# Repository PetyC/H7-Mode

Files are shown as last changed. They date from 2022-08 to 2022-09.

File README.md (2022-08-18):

<!--
 * @Description: Pi
 * @Autor: Pi
 * @Date: 2022-04-13 19:11:35
 * @LastEditTime: 2022-08-18 17:58:05
-->
# H7-Mode  
本项目名叫H7-Mode,顾名思义就是采用STM32H7作为MCU芯片进行相关设计开发的核心板和一些配套模组。  
意在实现具有联网、在线OTA升级、MQTT、LCD小屏状态显示等等功能的高性能面向自己的物联网开发核心套装，可根据不同要求设计不同底板以快速实现不同的功能。
因考虑到价格和设计难度，本项目使用芯片具体型号为STM32H7VIT6。
****

## 一、硬件部分
### 1.硬件结构
本项目目前分为H7-Core和H7-Network两个模块，Core实现核心功能，Network主要实现网络功能。
后续可能会加入更多的模块到该项目中以实现更多的功能  
模块之间通过FPC排线连接，并通过2.5mm螺柱固定成整体
### 2.整体外观  
本项目所设计PCB尺寸较小，长5cm 宽3cm。因考虑成本故只采用了双层板设计，也因此限搭载硬件资源有限。
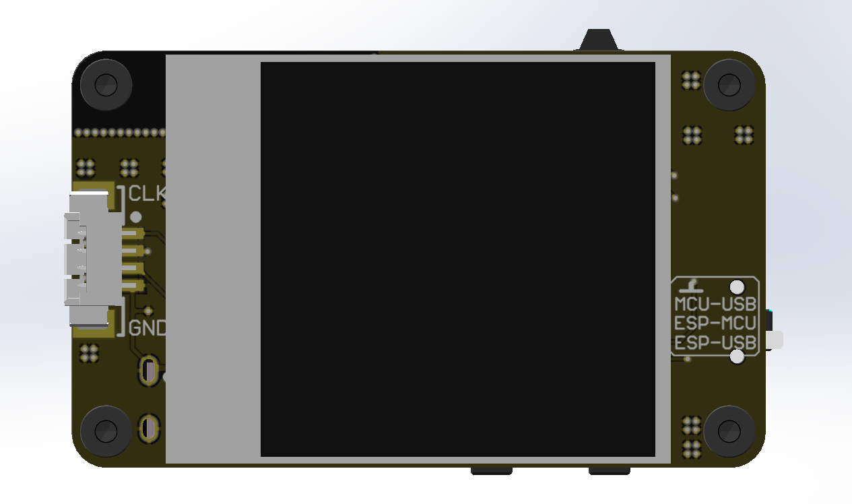
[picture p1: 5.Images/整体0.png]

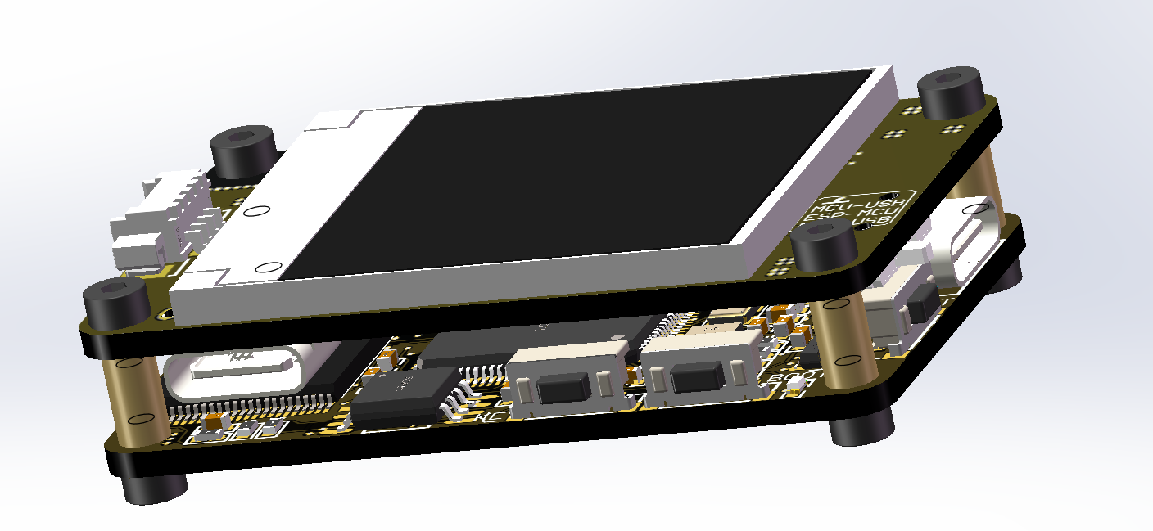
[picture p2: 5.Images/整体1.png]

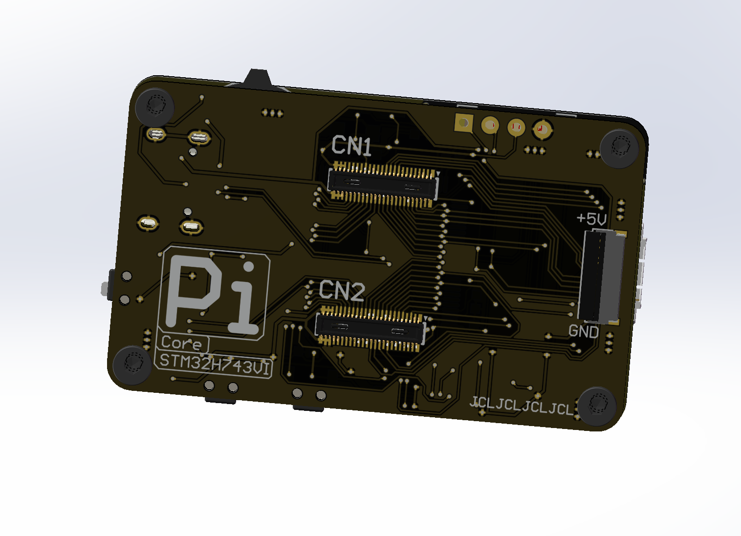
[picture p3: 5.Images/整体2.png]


****
### 2.硬件资源
#### 1.H7-Core
①MCU主频480MHZ 片内2MB FALSH、1MB RAM  
②板载高速、低速时钟  
③板载W25QXX FLASH 采用四线连接，走QSPI协议，芯片容量型号可自行更换  
④板载NAND FLASH  可做数据存储
⑤采用Type-C供电 支持USB2.0  
⑥共有3个按键，分别为:用户自定义按键、复位按键、一键进入Boot按键(即一键就可进入BOOT模式，无需长按或与复位键组合按)    
⑦2个LED，用户均可自定义功能  
⑧5V供电具有正反防短路电路，但需要注意3V3无任何保护  
⑨采用DC40F系列连接器，共引出80个IO和3V3，5V供电
#### 2.H7-Network
①MCU为ESP8266(可替换为ES8285) 使用26MHZ晶振  
②板载W25Q系列FLASH 采用4线连接，可使用QIO模式运行，FLASH型号可自行更换    
③板载陶瓷天线，比常见PCB天线信号更好  
④板载CP2102 USB转串口芯片  
⑤设计有自动下载电路，可实现固件自动下载  
⑥板载多通道开关芯片，可通过开关切换串口连接对象(MCU-ESP、MCU-CP2102、ESP-CP2102)，方便进行调试等工作  
⑦2个LED，用户均可自定义功能  
⑧板载3挡波轮开关，用户可自定义3挡功能  
⑨采用Type-C接口供电、连接电脑  
⑩搭载1.44寸TFT屏幕，其显示工作由H7-Core负责，本身未与ESP8266相连  

### 3.固件开发
#### 1.H7-Core    开发中  
整体框架使用STM32Cubmex+HAL进行开发（待续
#### 2.H7-Network 开发中  
整体框架在AT环境下进行开发，其使用源码为乐鑫提供的AT工程以实现一些自定义AT指令（待续

### 4.软件开发
#### 1.H7-Tool 微信小程序
初步实现配网功能，可使用微信小程序给H7-Mode设置WIFI网络信息，实现联网，界面如下  
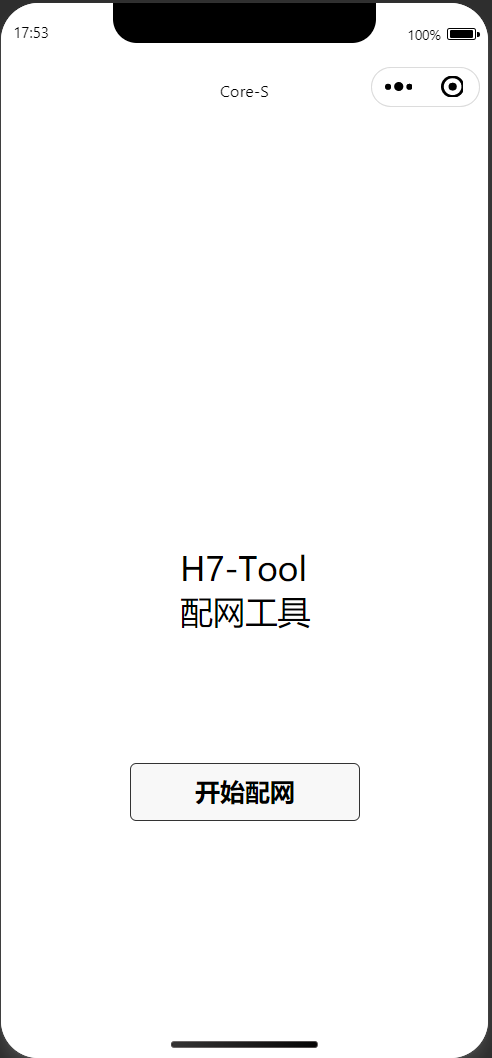
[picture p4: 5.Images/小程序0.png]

#### 2.待续  

### 4.待续待续待续待续
注:本项目所有资料尚未整理完毕

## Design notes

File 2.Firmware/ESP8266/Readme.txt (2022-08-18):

1、标准AT固件：存放有乐鑫官方提供的1.71版本AT固件
2、自定义AT固件: 存放有修改后的AT固件(1MB)
3、flash_download_tool_3.9.2 串口烧录工具
主要增加了按键检测功能和LED功能
按键检测:AT+KEY=1 启用，AT+KEY=0 关闭;
当有按键按下时，串口回复KEY:按键号\r\n

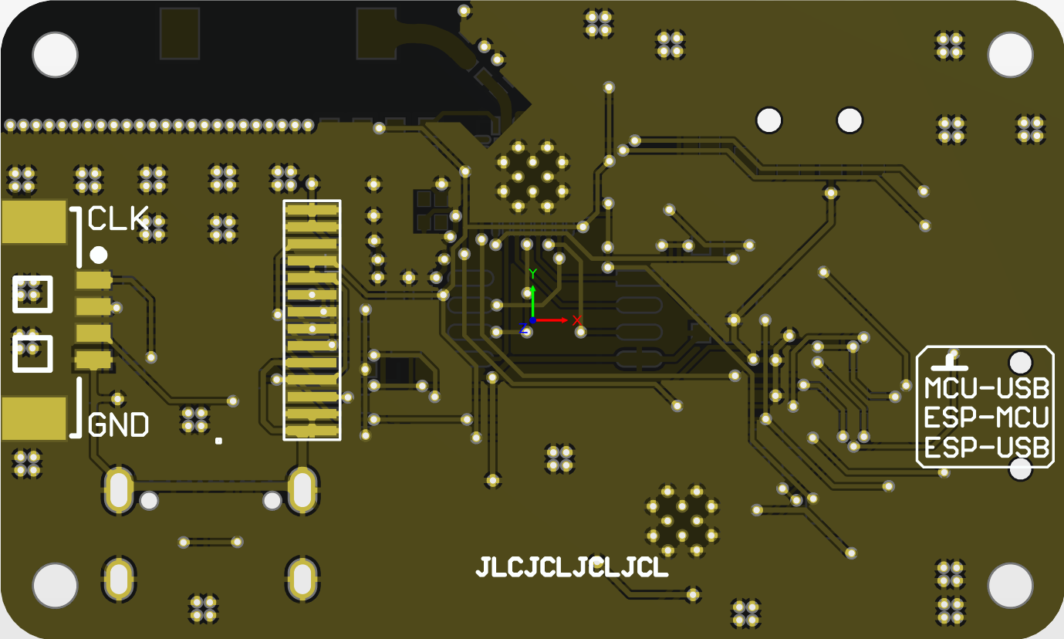
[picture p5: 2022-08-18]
1.Hardware/PCB_3D/PCB_Model/贴图/扩展版TOP贴图.png

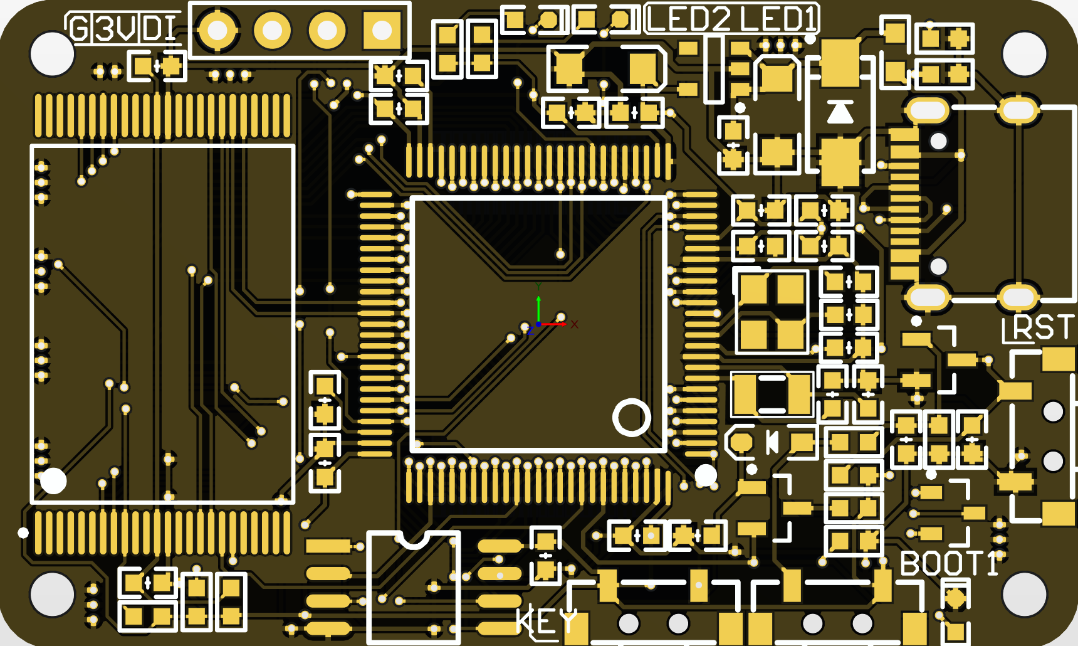
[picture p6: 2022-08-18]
1.Hardware/PCB_3D/PCB_Model/贴图/Core-TOP贴图.png

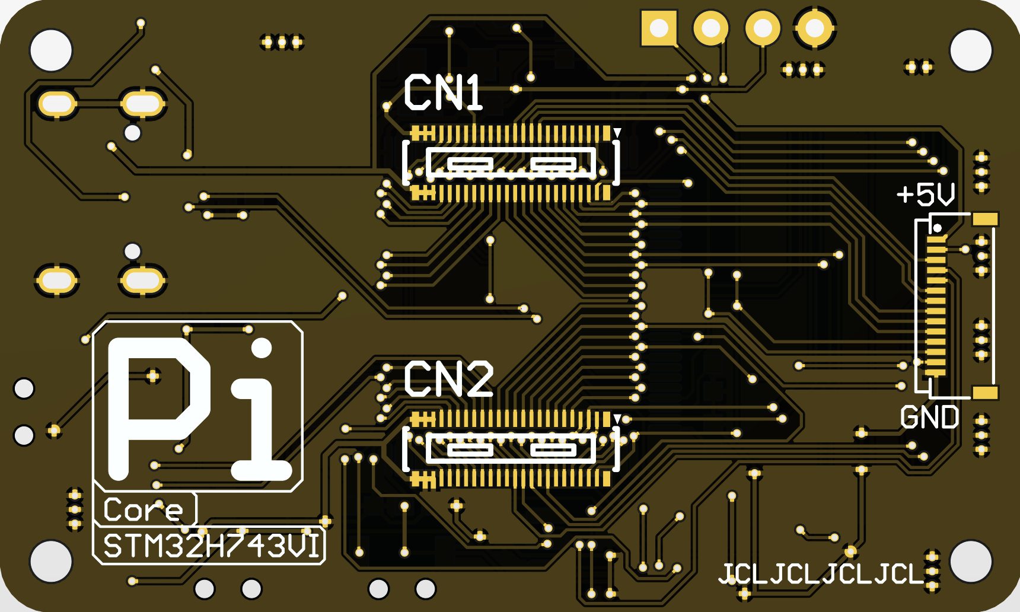
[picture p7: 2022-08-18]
1.Hardware/PCB_3D/PCB_Model/贴图/Core-Bottom贴图.png

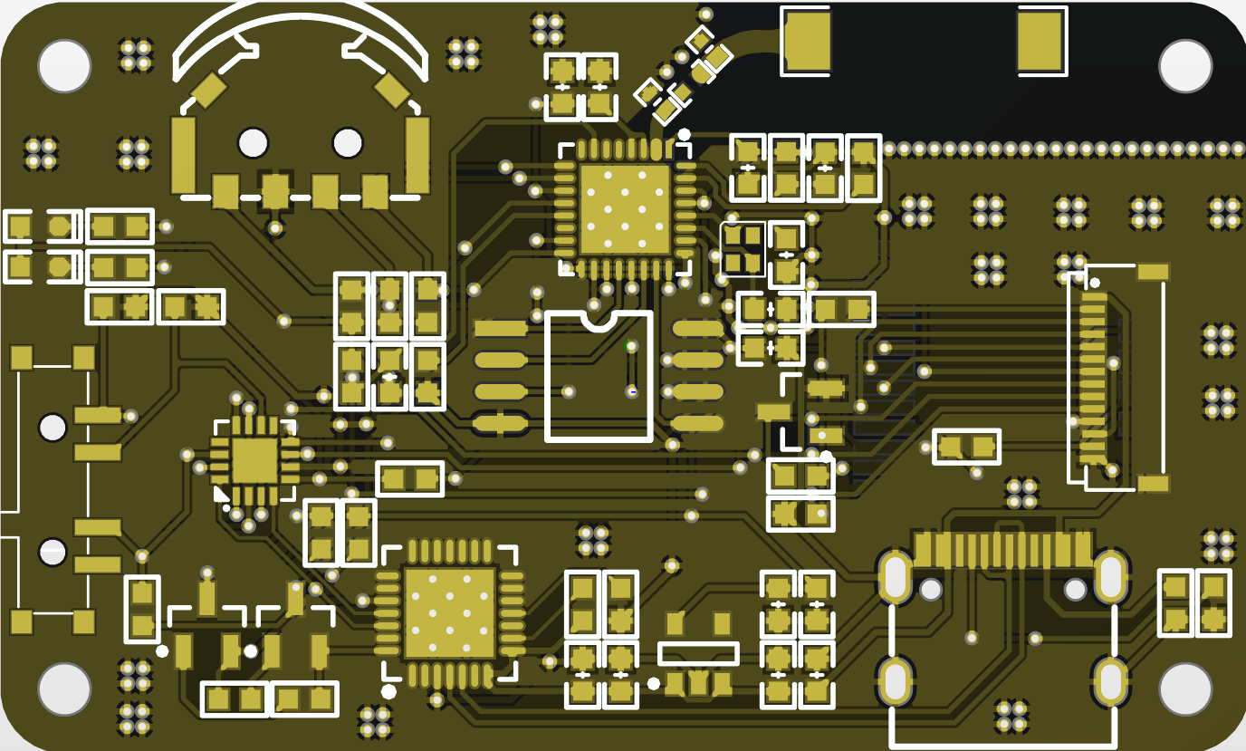
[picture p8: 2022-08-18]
1.Hardware/PCB_3D/PCB_Model/贴图/扩展版Bottom贴图.png

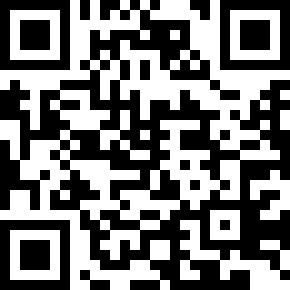
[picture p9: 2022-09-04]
2.Firmware/LVGL/CoreH7/generated/images/QR.png

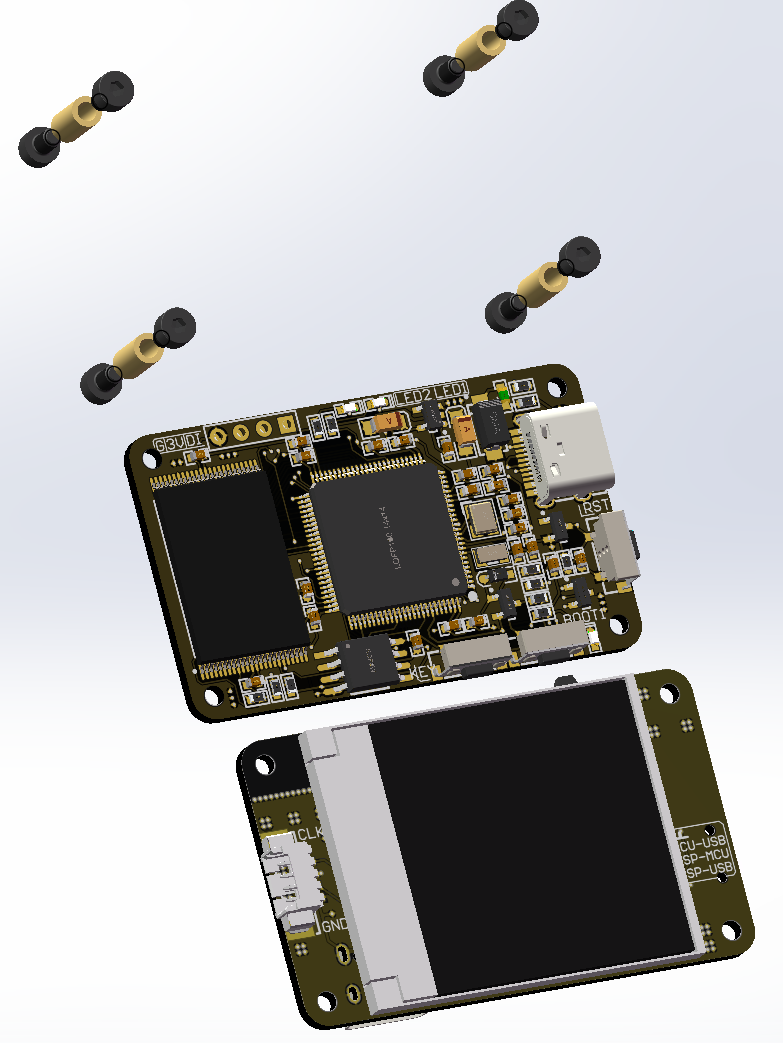
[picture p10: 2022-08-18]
5.Images/解体0.png

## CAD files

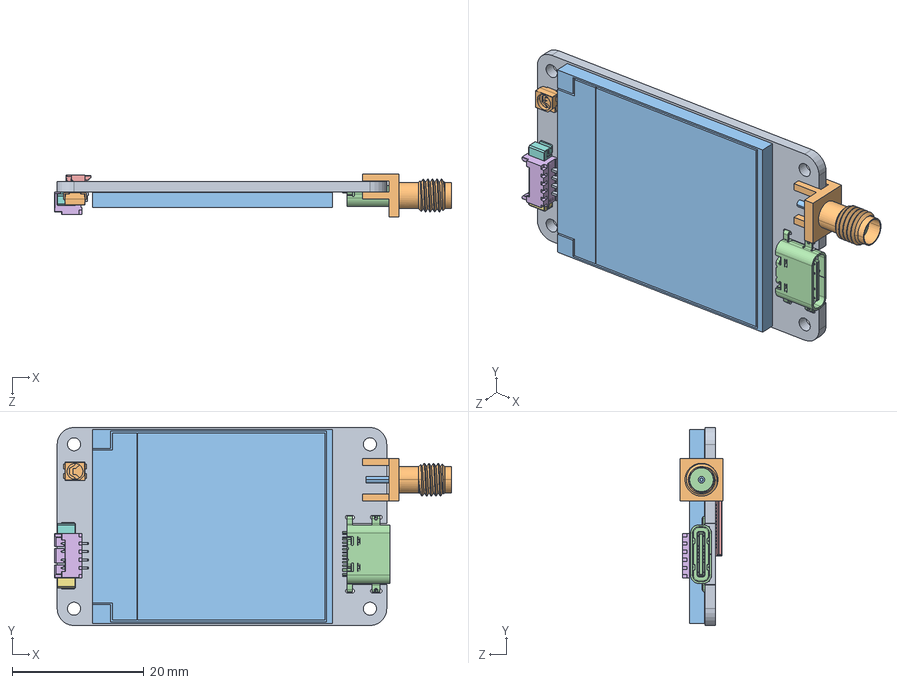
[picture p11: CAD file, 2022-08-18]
1.Hardware/PCB_3D/PCB_Model/Shape_Test.step.SLDASM
60.4 x 30.1 x 6.50 mm
_10001.step
_6_10001.step
_30001.step
FH34SRJ-14S-0.5SH(50).step
_12_1_2_AF0.step
4_1_200.step
1_1_200.step
MOLEX1_25-WS-_1_200.step x 4
LED_3528-4PIN_-675000.step
LCD_1.44.step
USB4505-03-0-A.step

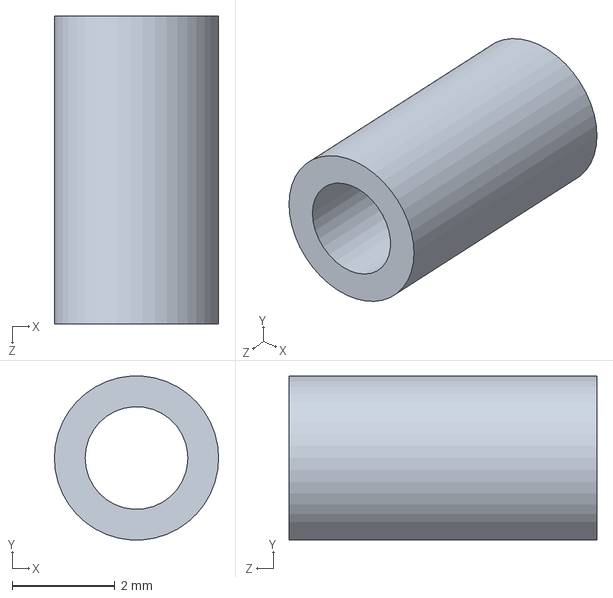
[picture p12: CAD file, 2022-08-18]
1.Hardware/PCB_3D/PCB_Model/M2铜柱.SLDPRT
3.20 x 3.19 x 6.00 mm

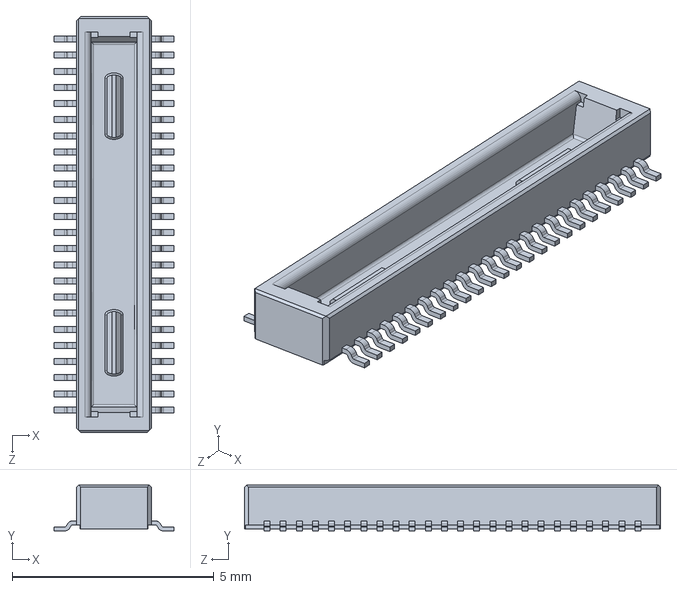
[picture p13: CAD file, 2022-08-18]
1.Hardware/PCB_3D/SLDPRT/DF40C-44DP.SLDPRT
2.97 x 1.14 x 10.3 mm

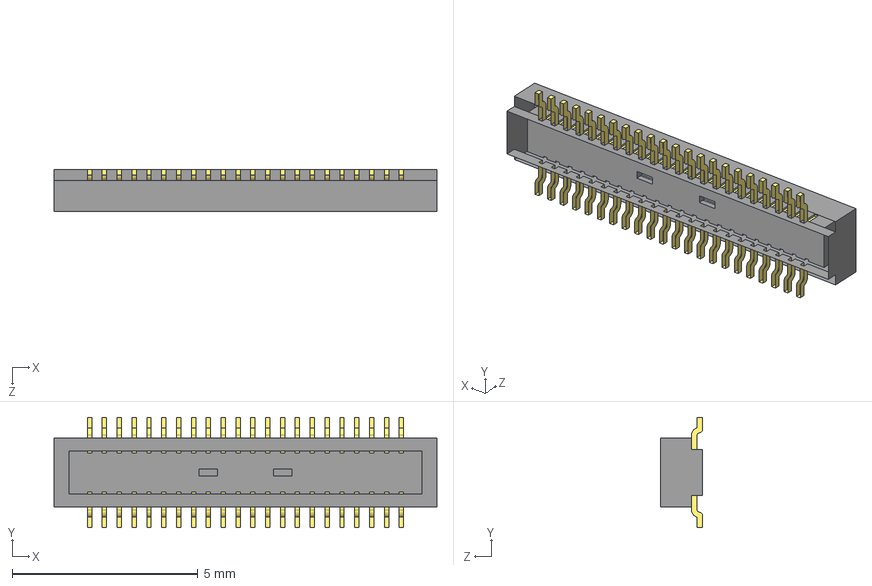
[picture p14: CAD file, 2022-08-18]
1.Hardware/PCB_3D/STEP/DF40C-44DP-0.4V.STEP
10.3 x 2.97 x 1.14 mm

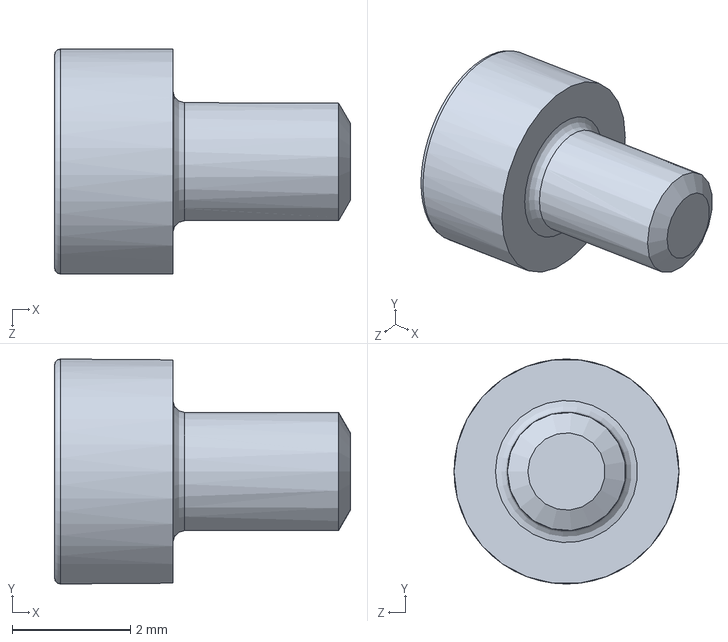
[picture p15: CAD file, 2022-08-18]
1.Hardware/PCB_3D/PCB_Model/内六角圆柱头螺钉M2.SLDPRT
5.00 x 3.80 x 3.80 mm

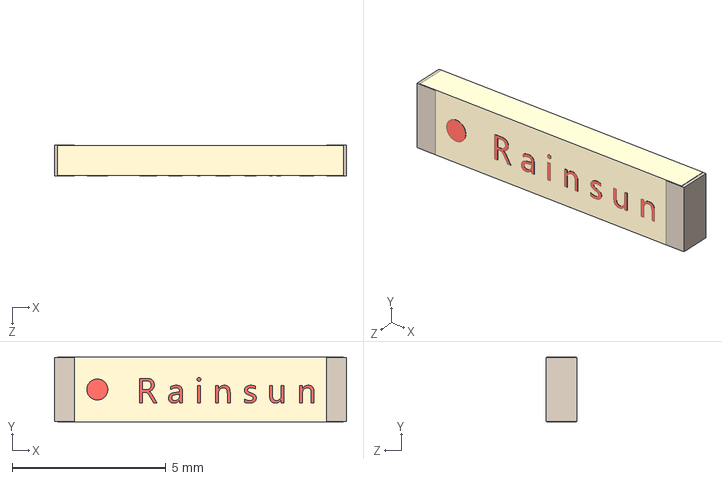
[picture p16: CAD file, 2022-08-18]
1.Hardware/PCB_3D/STEP/AN9520-245.STEP
9.50 x 2.10 x 1 mm

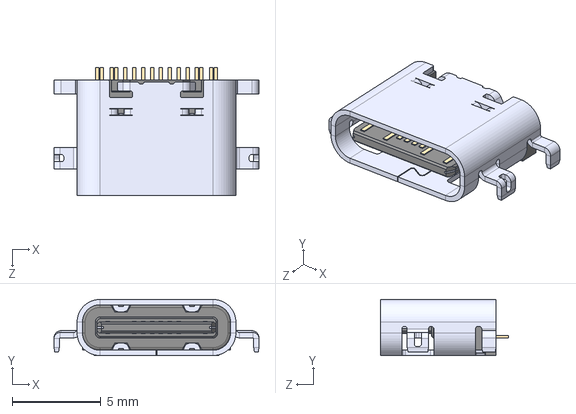
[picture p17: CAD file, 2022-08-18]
1.Hardware/PCB_3D/STEP/TYPE-C-16.STEP
11.5 x 3.16 x 7.20 mm

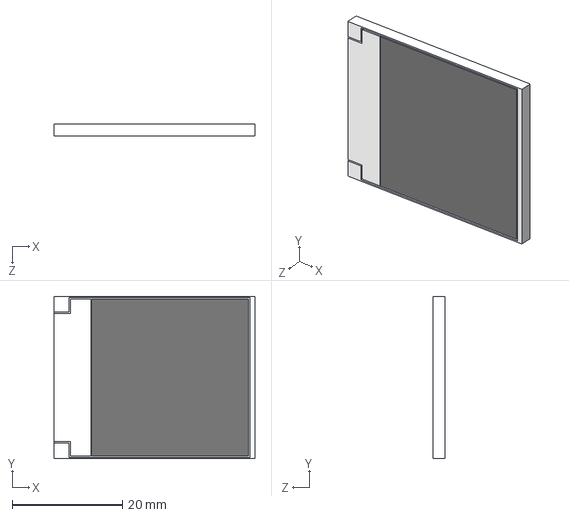
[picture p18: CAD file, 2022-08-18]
1.Hardware/PCB_3D/STEP/LCD_1.44.STEP
36.5 x 29.5 x 2.26 mm

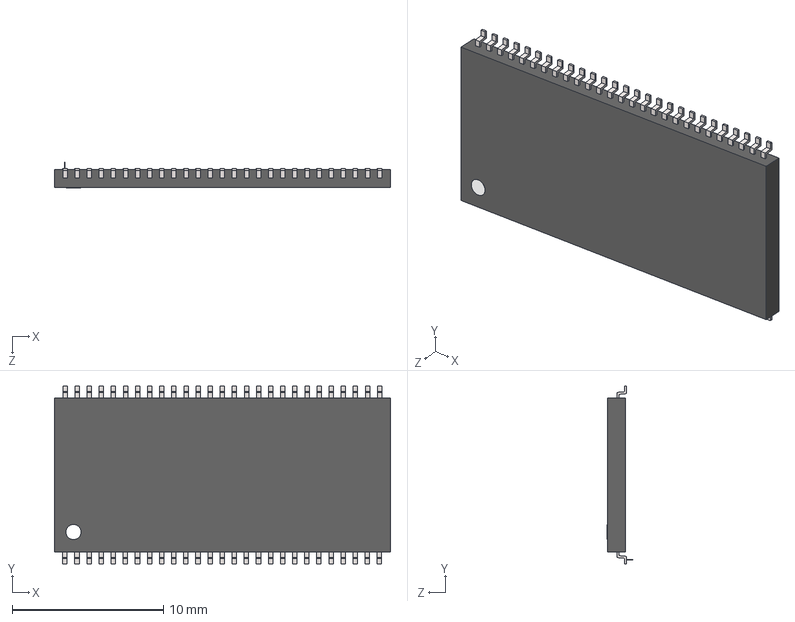
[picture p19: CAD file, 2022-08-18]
1.Hardware/PCB_3D/STEP/TSOP-54.STEP
22.2 x 11.8 x 1.70 mm
User Library-TSOP2-54-1_SW3dPS-TSOP2-54_Board5
User Library-TSOP2-54-1_SW3dPS-TSOP2-54_Extruded2 x 54
User Library-TSOP2-54-1_SW3dPS-TSOP2-54_Board4 x 54
User Library-TSOP2-54-1_SW3dPS-TSOP2-54_Extruded3
User Library-TSOP2-54-1_SW3dPS-TSOP2-54_Board7
User Library-TSOP2-54-1_SW3dPS-TSOP2-54_Cylinder1
User Library-TSOP2-54-1_SW3dPS-TSOP2-54_Board6

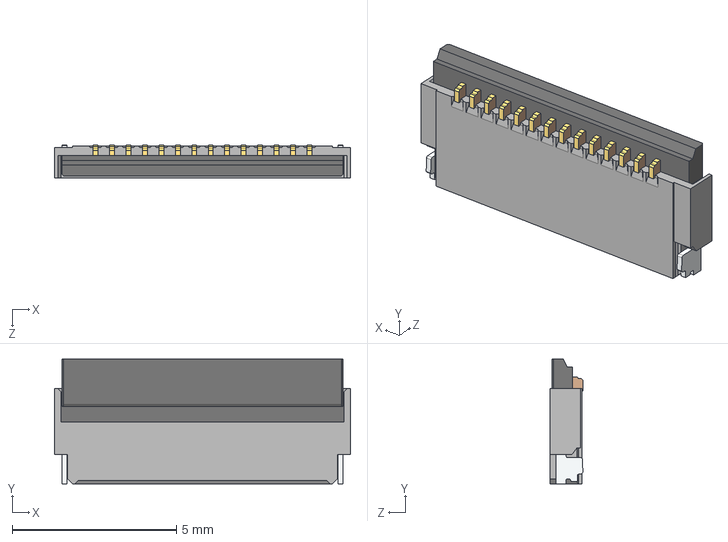
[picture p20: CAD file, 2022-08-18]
1.Hardware/PCB_3D/STEP/FH34SRJ-14S-0.5SH(50).STEP
9.00 x 3.80 x 1.00 mm

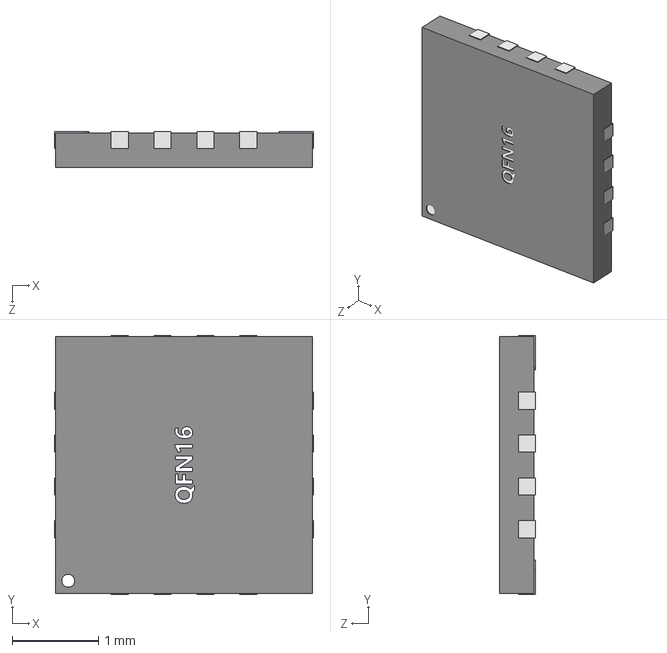
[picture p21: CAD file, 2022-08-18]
1.Hardware/PCB_3D/STEP/QFN16L-3X3.STEP
3.00 x 3.00 x 0.417 mm

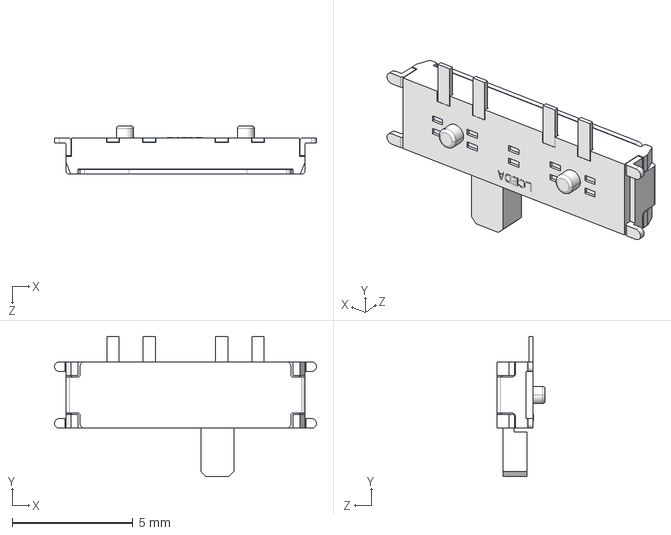
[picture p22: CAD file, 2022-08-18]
1.Hardware/PCB_3D/STEP/MSK13C02.STEP
10.8 x 5.80 x 2.00 mm

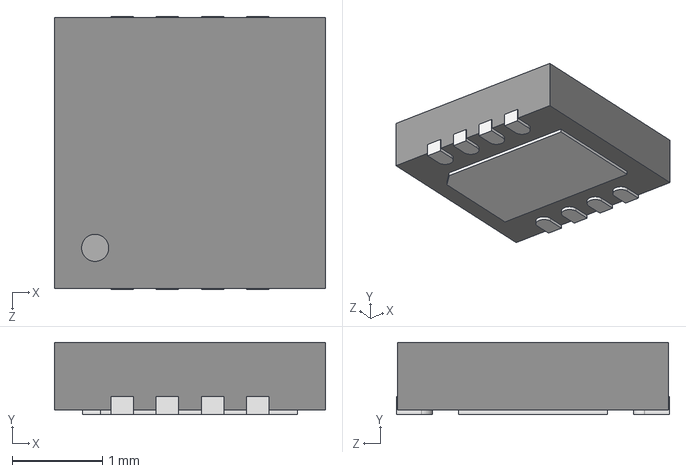
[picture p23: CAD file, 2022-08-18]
1.Hardware/PCB_3D/STEP/DFN-8.STEP
3.00 x 0.8 x 3.02 mm

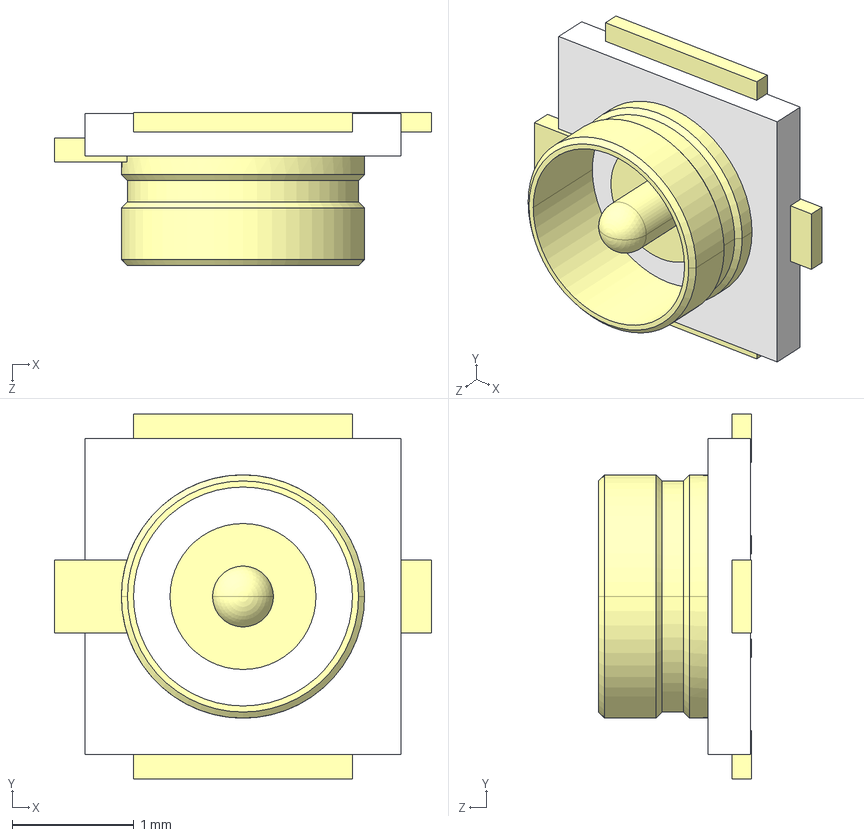
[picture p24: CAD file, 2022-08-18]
1.Hardware/PCB_3D/STEP/IPX座.STEP
3.10 x 3.00 x 1.26 mm

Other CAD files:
1.Hardware/PCB_3D/STEP/1612_26MHZ.STEP
1.Hardware/PCB_3D/STEP/MSK12C02.STEP
1.Hardware/PCB_3D/STEP/K3-2410S-F1.STEP
1.Hardware/PCB_3D/STEP/TM-2023.STEP
1.Hardware/PCB_3D/SLDPRT/1612_26MHZ.SLDPRT
1.Hardware/PCB_3D/SLDPRT/AN9520-245.SLDPRT
1.Hardware/PCB_3D/SLDPRT/DF40C-44DP-0.4V.SLDPRT
1.Hardware/PCB_3D/SLDPRT/FH34SRJ-14S-0.5SH(50).SLDPRT
1.Hardware/PCB_3D/SLDPRT/IPX座.SLDPRT
1.Hardware/PCB_3D/SLDPRT/K3-2410S-F1.SLDPRT
1.Hardware/PCB_3D/SLDPRT/LCD_1.44.SLDPRT
1.Hardware/PCB_3D/SLDPRT/MSK12C02.SLDPRT
1.Hardware/PCB_3D/SLDPRT/MSK13C02.SLDPRT
1.Hardware/PCB_3D/SLDPRT/QFN16L-3X3.SLDPRT
1.Hardware/PCB_3D/SLDPRT/TM-2023.SLDPRT

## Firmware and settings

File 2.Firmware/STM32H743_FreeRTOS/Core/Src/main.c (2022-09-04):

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
/* Includes ------------------------------------------------------------------*/
#include "main.h"
#include "cmsis_os.h"
#include "adc.h"
#include "dma.h"
#include "mdma.h"
#include "quadspi.h"
#include "spi.h"
#include "tim.h"
#include "usart.h"
#include "usb_otg.h"
#include "gpio.h"
#include "fmc.h"

/* USER CODE BEGIN Includes */
//#include "st7735s.h"
#include "Bsp_ESP8266.h"
#include "Bsp_w25qxx.h"
#include "Bsp_Nand_Flash.h"

/* USER CODE END Includes */


void SystemClock_Config(void);
void PeriphCommonClock_Config(void);
void MX_FREERTOS_Init(void);
/* USER CODE BEGIN 0 */
 
//static uint8_t FLASH_Buff[256] __attribute__((section(".ARM.__at_0x24001400"))); 

/* USER CODE END 0 */

/**
  * @brief  The application entry point.
  * @retval int
  */
int main(void)
{
  /* USER CODE BEGIN 1 */
  /*设置中断偏移*/
 // SCB->VTOR = FLASH_BASE | 0x100000;  
  
  /* USER CODE END 1 */

  /* MCU Configuration--------------------------------------------------------*/

  /* Reset of all peripherals, Initializes the Flash interface and the Systick. */
  HAL_Init();

  /* Configure the system clock */
  SystemClock_Config();

/* Configure the peripherals common clocks */
  PeriphCommonClock_Config();

  /* Initialize all configured peripherals */
  MX_GPIO_Init();
  MX_DMA_Init();
  MX_USART1_UART_Init();
  MX_QUADSPI_Init();
  MX_MDMA_Init();
  MX_SPI1_Init();
  MX_USB_OTG_FS_PCD_Init();
  MX_FMC_Init();
  MX_TIM14_Init();
  MX_TIM1_Init();
  MX_TIM13_Init();
  MX_ADC3_Init();
  /* USER CODE BEGIN 2 */
  /*MCU系统占用�??*/
  HAL_TIM_Base_Start_IT(&htim14);

  /*打开网络超时定时�??*/
  HAL_TIM_Base_Start_IT(&htim13);
  
 // LCD_Init();
  
 // QSPI_W25Qx_Init();
  
  Bsp_Nand_Init();
  

  
  while(1);
  /* USER CODE END 2 */

  /* Call init function for freertos objects (in freertos.c) */
  MX_FREERTOS_Init();

  /* Start scheduler */
  osKernelStart();

  /* We should never get here as control is now taken by the scheduler */
  /* Infinite loop */
  /* USER CODE BEGIN WHILE */
  while (1)
  {
    /* USER CODE END WHILE */

    /* USER CODE BEGIN 3 */
  }
  /* USER CODE END 3 */
}

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
/* USER CODE BEGIN 4 */
extern volatile uint32_t ulHighFrequencyTimerTicks;
/* USER CODE END 4 */

/**
  * @brief  Period elapsed callback in non blocking mode
  * @note   This function is called  when TIM17 interrupt took place, inside
  * HAL_TIM_IRQHandler(). It makes a direct call to HAL_IncTick() to increment
  * a global variable "uwTick" used as application time base.
  * @param  htim : TIM handle
  * @retval None
  */
void HAL_TIM_PeriodElapsedCallback(TIM_HandleTypeDef *htim)
{
  if (htim->Instance == TIM17) {
    HAL_IncTick();
  }
  /* USER CODE BEGIN Callback 1 */
  if (htim->Instance == TIM14) 
  {
    ulHighFrequencyTimerTicks++;
  }
  if(htim->Instance == TIM13)
  {
    Bsp_ESP8266_Timer();
  }
  /* USER CODE END Callback 1 */
}

/**
  * @brief  This function is executed in case of error occurrence.
  * @retval None
  */
void Error_Handler(void)
{
  /* USER CODE BEGIN Error_Handler_Debug */
  /* User can add his own implementation to report the HAL error return state */
  __disable_irq();
  while (1)
  {
  }
  /* USER CODE END Error_Handler_Debug */
}

#ifdef  USE_FULL_ASSERT
/**
  * @brief  Reports the name of the source file and the source line number
  *         where the assert_param error has occurred.
  * @param  file: pointer to the source file name
  * @param  line: assert_param error line source number
  * @retval None
  */
void assert_failed(uint8_t *file, uint32_t line)
{
  /* USER CODE BEGIN 6 */
  /* User can add his own implementation to report the file name and line number,
     ex: printf("Wrong parameters value: file %s on line %d\r\n", file, line) */
  /* USER CODE END 6 */
}
#endif /* USE_FULL_ASSERT */

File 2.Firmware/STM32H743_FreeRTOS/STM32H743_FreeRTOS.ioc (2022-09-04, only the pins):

Mcu.UserName=STM32H743VITx
PA0.GPIO_Label=KEY
PA0.Signal=GPIO_Input
PA1.Signal=QUADSPI_BK1_IO3
PA11.Signal=USB_OTG_FS_DM
PA12.Signal=USB_OTG_FS_DP
PA4.Signal=SPI1_NSS
PA8.GPIO_Label=LCD_BLK
PA8.Signal=S_TIM1_CH1
PB0.GPIO_Label=LCD_DC
PB0.Signal=GPIO_Output
PB1.GPIO_Label=LCD_RES
PB1.Signal=GPIO_Output
PB14.Signal=USART1_TX
PB15.Signal=USART1_RX
PB2.Signal=QUADSPI_CLK
PB6.Signal=QUADSPI_BK1_NCS
PC10.Signal=QUADSPI_BK1_IO1
PC4.GPIO_Label=LED1
PC4.Signal=GPIO_Output
PC5.GPIO_Label=LED2
PC5.Signal=GPIO_Output
PC8.Signal=FMC_NCE
PC9.Signal=QUADSPI_BK1_IO0
PD0.Signal=FMC_D2_DA2
PD1.Signal=FMC_D3_DA3
PD11.Signal=FMC_A16_CLE
PD12.Signal=FMC_A17_ALE
PD14.Signal=FMC_D0_DA0
PD15.Signal=FMC_D1_DA1
PD4.Signal=FMC_NOE
PD5.Signal=FMC_NWE
PD6.Signal=FMC_NWAIT
PD7.Signal=SPI1_MOSI
PD8.GPIO_Label=ESP_POW
PD8.Signal=GPIO_Output
PE10.Signal=FMC_D7_DA7
PE2.Signal=QUADSPI_BK1_IO2
PE7.Signal=FMC_D4_DA4
PE8.Signal=FMC_D5_DA5
PE9.Signal=FMC_D6_DA6

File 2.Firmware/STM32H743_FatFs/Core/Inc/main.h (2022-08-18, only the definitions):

#define KEY_Pin GPIO_PIN_0
#define KEY_GPIO_Port GPIOA
#define LED1_Pin GPIO_PIN_4
#define LED1_GPIO_Port GPIOC
#define LED2_Pin GPIO_PIN_5
#define LED2_GPIO_Port GPIOC
#define LCD_DC_Pin GPIO_PIN_0
#define LCD_DC_GPIO_Port GPIOB
#define LCD_RES_Pin GPIO_PIN_1
#define LCD_RES_GPIO_Port GPIOB
#define ESP_POW_Pin GPIO_PIN_8
#define ESP_POW_GPIO_Port GPIOD
#define LCD_BLK_Pin GPIO_PIN_8
#define LCD_BLK_GPIO_Port GPIOA

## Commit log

2022-08-18 更新简介
2022-08-18 尝试一直lvgl
2022-08-19 ST7735S 尝试改用DMA
2022-08-21 更改Network原理图C2电容为0.1uf，解决下载不稳定问题
    [H7-Network.SchDoc]
2022-08-22 尝试添加LVGL
    [H7-Network.SchDoc]
2022-08-22 移植LVGL工程
2022-08-23 LVGL加入工厂
2022-08-24 添加LVGL工程
2022-08-25 添加波轮
2022-08-26 修复LCD显示错误BUG
2022-08-27 LVGL版本改用V8.2以配合GUI GUIDER
2022-08-27 添加内部温度
2022-08-28 滚动存疑
2022-08-30 添加WIFI图标
2022-08-31 优化QSPI
2022-08-31 增加QFLASH测试功能
2022-08-31 优化QSPI测速函数
2022-09-01 添加NAND FLASH
2022-09-01 nand flash需要关闭中断读写
2022-09-04 淼此重构
    [H7-Core.SchDoc]

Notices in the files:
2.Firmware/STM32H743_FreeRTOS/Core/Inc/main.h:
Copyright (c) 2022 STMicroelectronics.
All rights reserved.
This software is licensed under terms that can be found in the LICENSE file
